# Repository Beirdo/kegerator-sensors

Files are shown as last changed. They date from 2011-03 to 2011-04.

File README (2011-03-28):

This project is licensed under the terms of GPLv2.

The hardware design was completed using the geda toolset, and my test boards
are being made by batchpcb.com.  Almost all parts purchased from digikey.com.

I will add bill of materials, etc later as time allows.

The firmware for the sensors and receiver uses the gcc-avr and avr-libc
packages for building, and avrdude for programming (with a buspirate
programmer).

In ubuntu, you will need the following debs:

For firmware:
avr-libc
avrdude
avrdude-doc
binutils-avr
gcc-avr
gdb-avr
simulavr

For schematic/circuit board:
geda
geda-doc
geda-examples
geda-gattrib
geda-gnetlist
geda-gschem
geda-gsymcheck
geda-symbols
geda-utils
gerbv
pcb
pcb-common
pcb-gtk
zip

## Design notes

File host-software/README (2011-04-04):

The host-side hardware is targeted to an ARM9TDMI board with a 3.5" touchscreen
LCD.  It can be found at:

	http://www.andahammer.com/mini35-sdk/

This board will be running Linux, and a cross-compiler suite was generated
using crosstool-ng which can be found at:

	http://ymorin.is-a-geek.org/download/crosstool-ng/

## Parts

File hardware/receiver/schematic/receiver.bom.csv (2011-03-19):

Refdes | Qty | Value | Digikey Part | Manufacturer | Manufacturer Part | Footprint | Description
CONN1,CONN2,CONN3 | 1 |  | 768-1021-ND | FTDI | MM232R |  | The jumper connectors come with the RS232-USB module
CONN4 | 1 |  | SAM1034-03-ND | Samtech | TSW-103-07-T-D | 6 pos 100" dual row | 2x3 male header
CONN5 | 1 |  | AE10334-ND | Assmann | AU-Y1008-2-R | custom | USB stacked dual-A connector
C1,C2 | 2 | 0.1uF 50V | 709-1189-1-ND | Johanson Dielectric | 500R15W104KV4T | 0805 | Capacitor Ceramic 0.1uF 50V X7R 0805
R1,R2,R3 | 3 | TBD | TBD | TBD | TBD | 0805 | Resistor Surface Mount 0805
U1 | 1 |  | ATMEGA128A-AU-ND | Atmel | ATMEAGA128A-AU | TQFP-64 | MCU 8bit 128K ISP FLASH 64-TQFP
U2 | 1 |  | TCN75AVOA-ND | Microchip | TCN75AVOA | SO-8 | IC Temp Sensor I2C 2.7V 8SOIC
U3 | 1 |  | DS92LV010ATM-ND | National Semiconductor | DS92LV010ATM | SO-8 | IC TXRX Bus LVDS Single 8SOIC

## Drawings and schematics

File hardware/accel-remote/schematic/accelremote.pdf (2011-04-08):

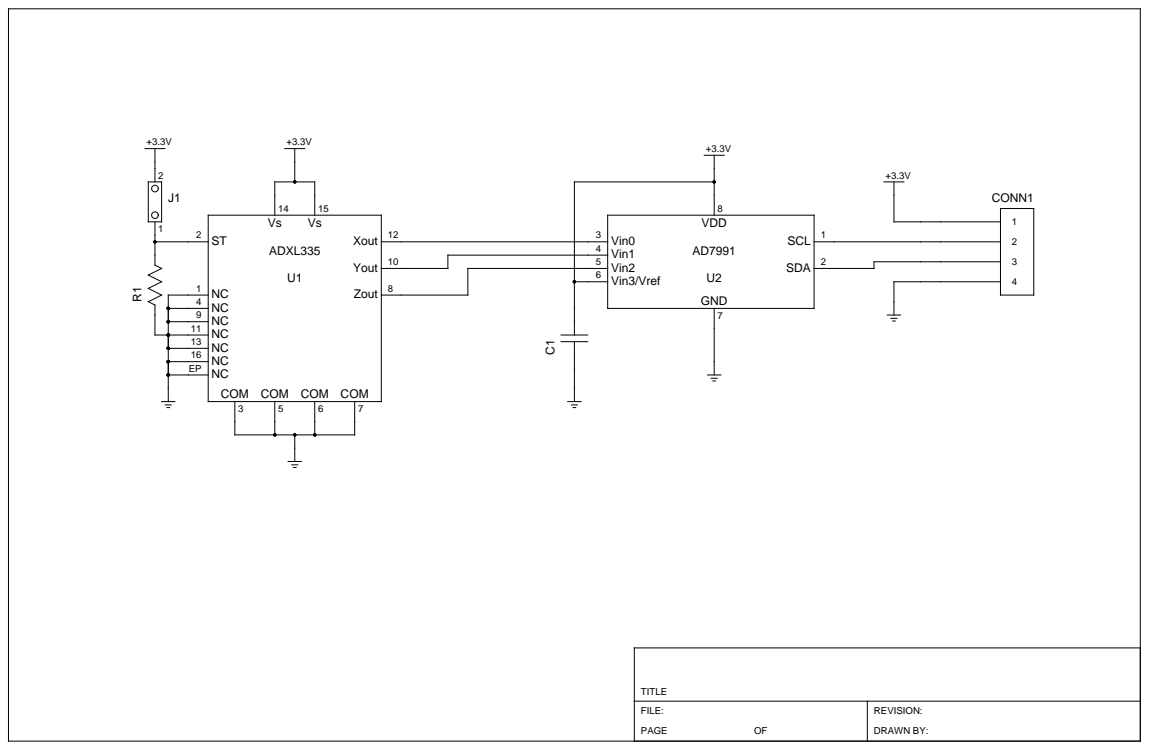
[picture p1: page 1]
PAGE; DRAWN BY:; Vin0 3; Vin3/Vref 6

NC 1 | | Vin1 4

Vin2 5

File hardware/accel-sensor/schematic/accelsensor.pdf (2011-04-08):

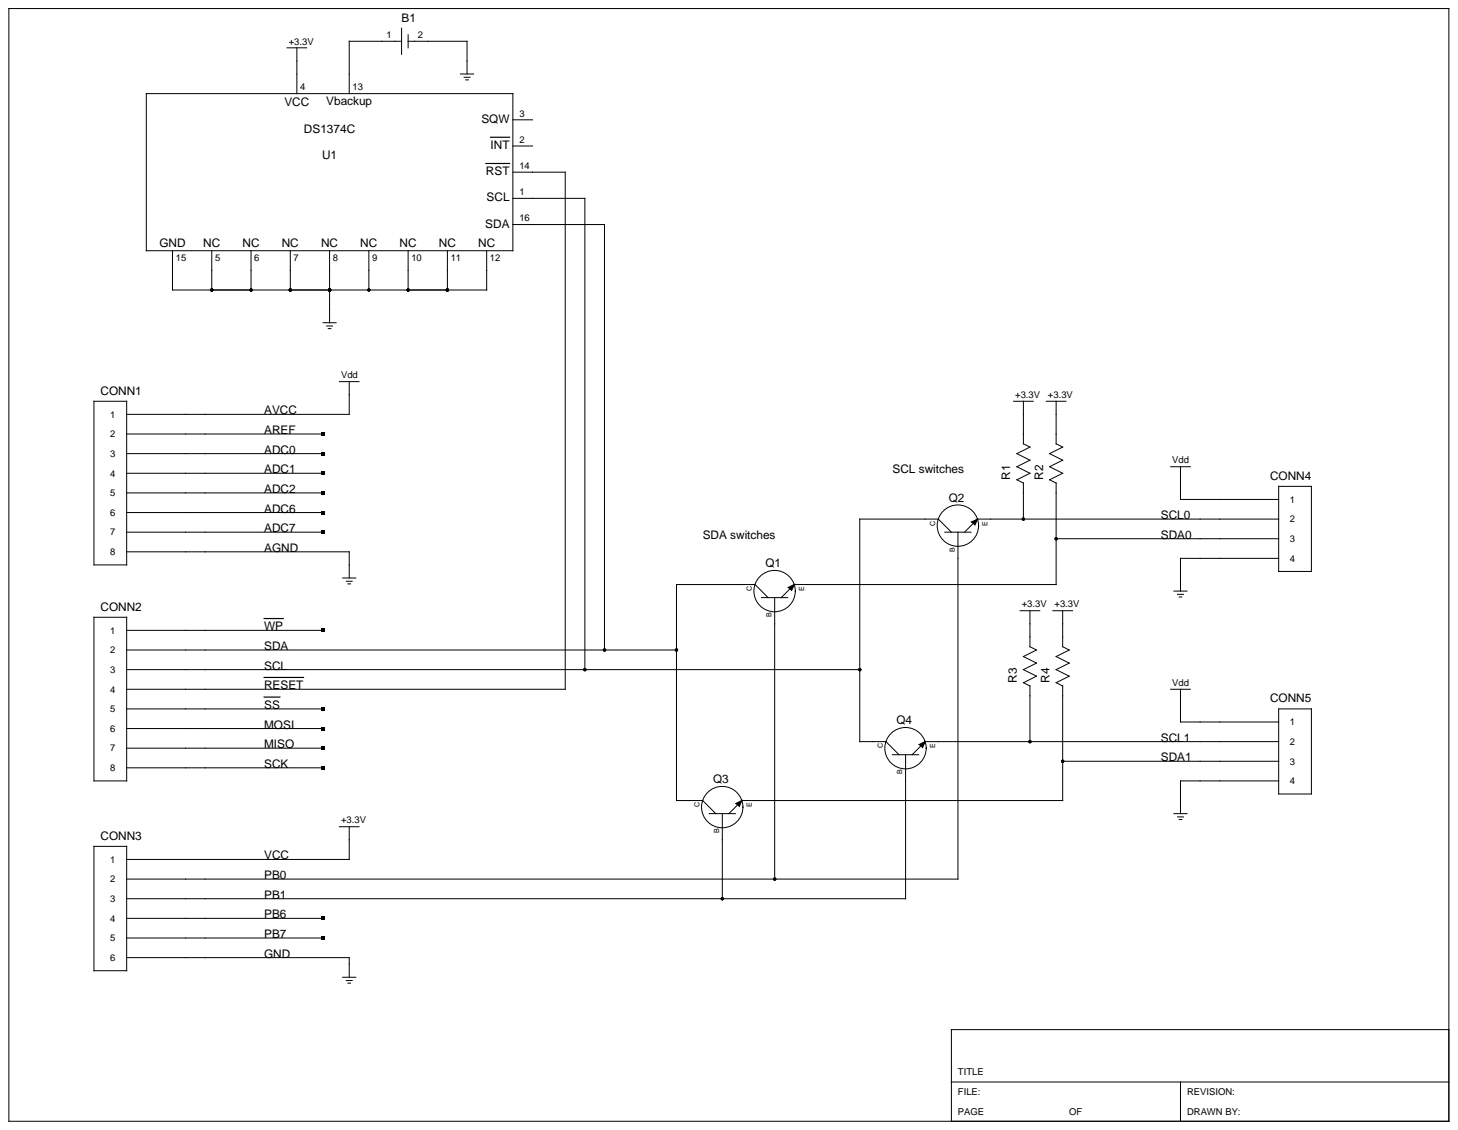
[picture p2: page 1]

SCL
RESET

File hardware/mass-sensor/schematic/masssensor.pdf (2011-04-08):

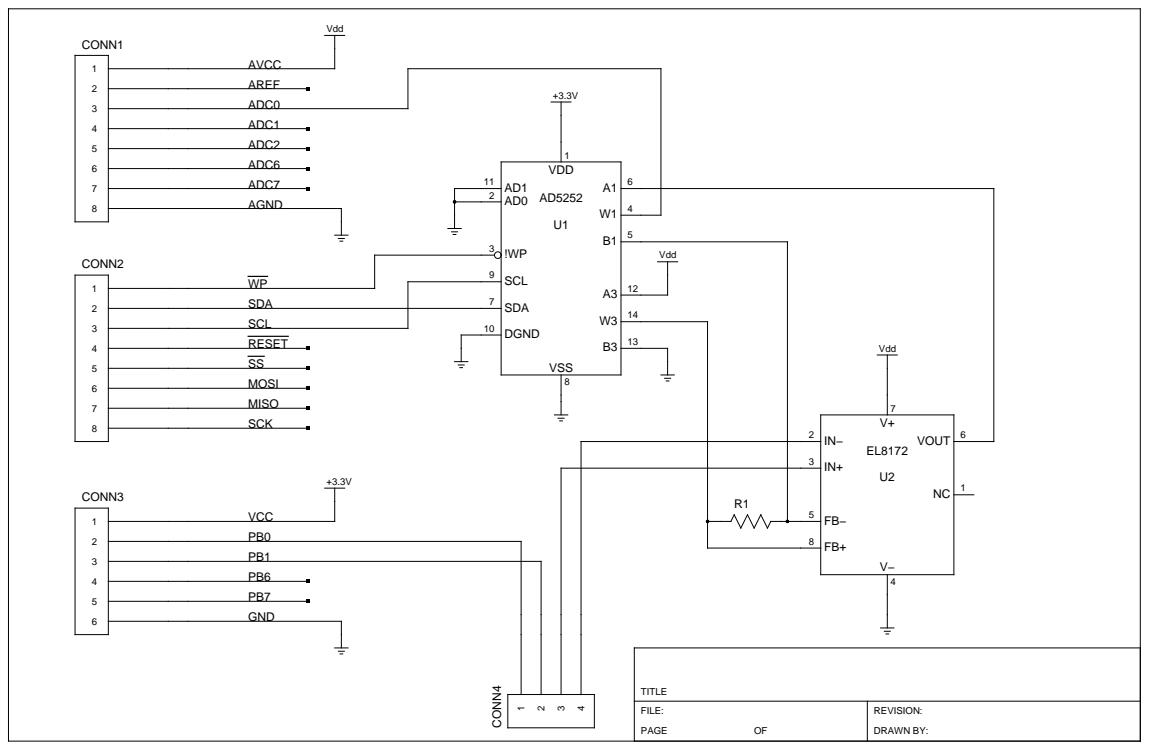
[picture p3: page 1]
PAGE; DRAWN BY:; DGND 10

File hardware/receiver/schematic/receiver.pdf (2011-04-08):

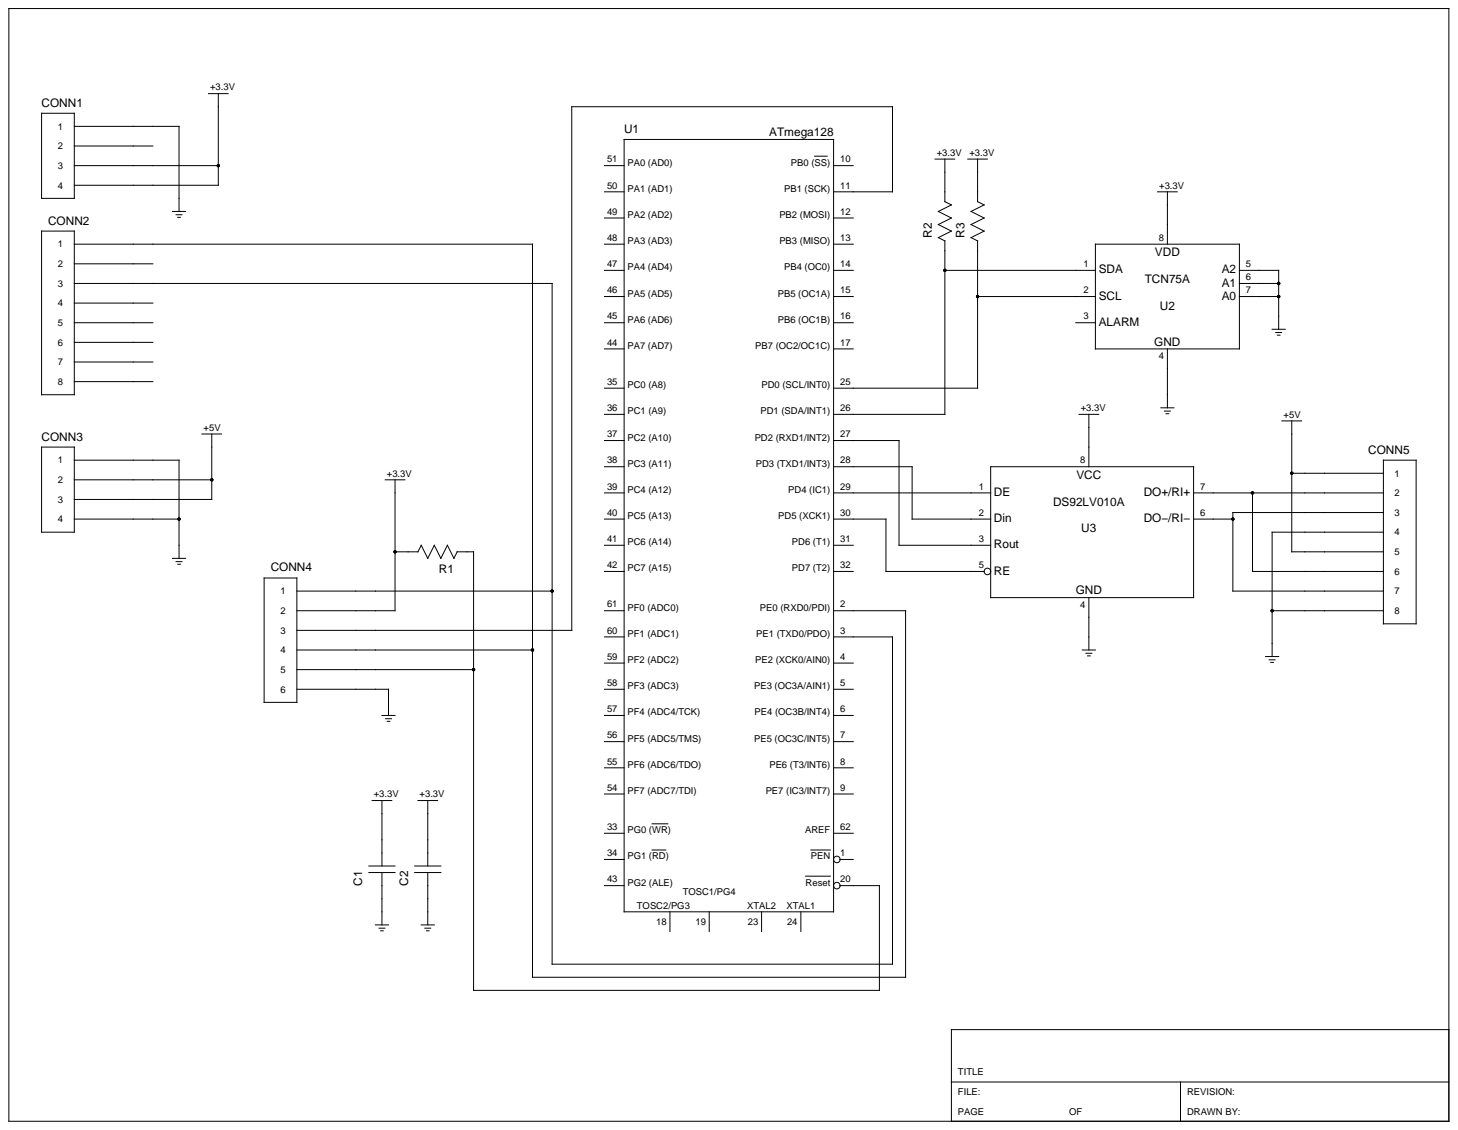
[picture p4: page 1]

30 PD5 (XCK1) | | Din 2

31 PD6 (T1) 32 PD7 (T2) 2 PE0 (RXD0/PDI) | Rout 3

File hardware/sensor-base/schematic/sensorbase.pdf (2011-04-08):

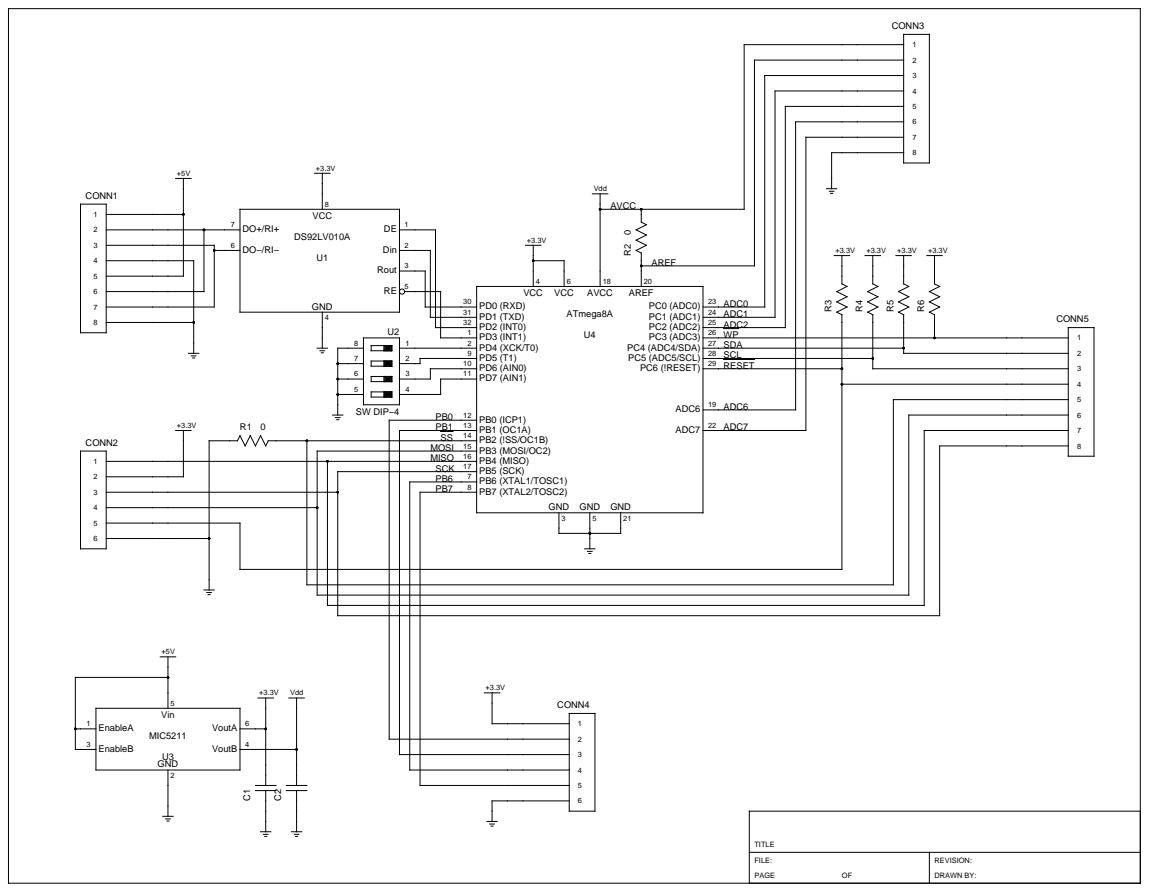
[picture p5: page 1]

SCK | PB5 (SCK) 17
PB6 | PB6 (XTAL1/TOSC1) 7

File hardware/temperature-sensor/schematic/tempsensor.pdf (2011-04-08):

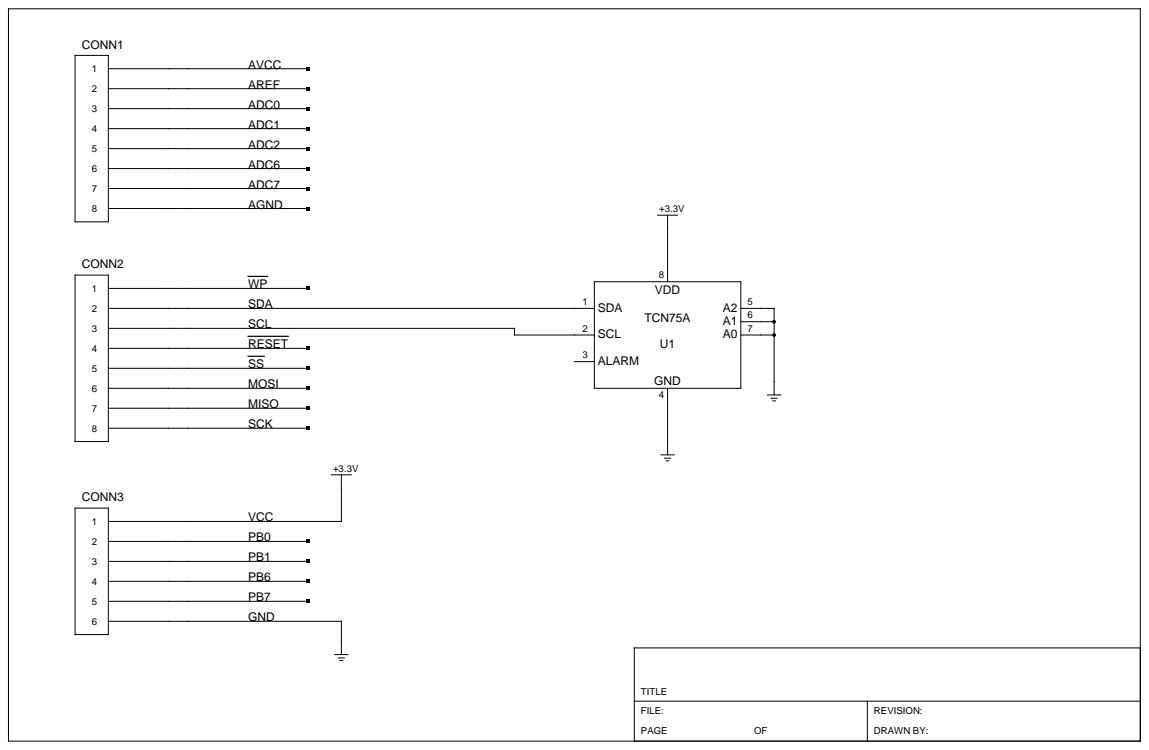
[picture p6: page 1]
PAGE; DRAWN BY:

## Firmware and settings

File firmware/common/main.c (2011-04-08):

#include "local.h"
#include <avr/io.h>
#include <avr/interrupt.h>
#include <avr/sleep.h>
#include <avr/signature.h>
#include <avr/fuse.h>
#include <util/delay.h>
#include <stdint.h>

FUSES =
{
    .low = (FUSE_CKSEL3 & FUSE_CKSEL1 & FUSE_CKSEL0 & FUSE_SUT1), 
    /* & FUSE_SUT0 & FUSE_BODEN), */
    .high = HFUSE_DEFAULT,
#if FUSE_MEMORY_SIZE == 3
    .extended = 0xFF,
#endif
};


int main(void) __attribute__((noreturn));

int main(void)
{
    cli();

    uart_setup();
    timer_setup();
    i2c_setup();
    sensor_main_setup();

    set_sleep_mode(SLEEP_MODE_IDLE);

    _delay_ms(10);

    sei();

    sensor_local_setup();

    /* Sit on this and rotate, don't return */
    while(1)
    {
        sleep_mode(); 

        if( sensor_in_use )
        {
            sensor_handle();
        }
    }
}

/*
 * vim:ts=4:sw=4:ai:et:si:sts=4
 */

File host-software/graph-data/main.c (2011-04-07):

#include <string.h>
#include <stdio.h>
#include <stdint.h>
#include <cgi.h>
#include <stdlib.h>
#include <sys/types.h>
#include <sys/stat.h>
#include <fcntl.h>
#include <unistd.h>
#include "local.h"

int main( int argc, char **argv )
{
    char   *param;
    int     sensornum;
    int     subaddr;
    int     days;
    int     type;

    cgi_init();
    cgi_process_form();

    param = cgi_param("sensor");
    sensornum = param ? atoi(param) : 255;

    param = cgi_param("type");
    type = param ? atoi(param) : S_RECEIVER;

    param = cgi_param("subaddr");
    subaddr = param ? atoi(param) : 1;

    param = cgi_param("days");
    days = param ? atoi(param) : 1;

    load_data(sensornum, subaddr, type, days );
    create_graph();

    cgi_redirect(graphuri);

    cgi_end();
    return( 0 );
}

/*
 * vim:ts=4:sw=4:ai:et:si:sts=4
 */

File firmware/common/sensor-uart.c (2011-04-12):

#include "local.h"
#include <avr/io.h>
#include <avr/interrupt.h>
#include <stdint.h>
#include <string.h>

/* 38400 to the sensors over BLVDS */
#define BAUD 38400
#include <util/setbaud.h>

uint8_t u_rx_buf[MAX_BUF_LEN];
uint8_t u_rx_index;
uint8_t u_rx_size;
uint8_t u_tx_buf[MAX_BUF_LEN];
uint8_t u_tx_index;
uint8_t u_tx_size;
uint8_t ucsra_val;

void uart_setup(void)
{
    UBRRH = UBRRH_VALUE;
    UBRRL = UBRRL_VALUE;
#if USE_2X
    ucsra_val = (1 << U2X) | (1 << MPCM);
#else
    ucsra_val = (1 << MPCM);
#endif
    UCSRA = ucsra_val;

    UCSRB = (1 << RXCIE) | (1 << RXEN) | (1 << TXEN) | (1 << UCSZ2); 
    UCSRC = (1 << URSEL) | (3 << UCSZ0);                  /* N91 */

    /* Setup the enables for the BLVDS part */
    DDRD  |= (1 << PD3) | (1 << PD2);

    /* Enable the reciever, disable the transmitter */
    PORTD &= ~((1 << PD3) | (1 << PD2));

    u_rx_index = 0;
    u_rx_size  = MAX_BUF_LEN;
    u_tx_index = 0;
}

void uart_rx_timeout(void)
{
    timer_disable();
    u_rx_index = 0;
    UCSRA = ucsra_val;
}


/* UART Rx interrupt */
ISR(SIG_UART_RECV)
{
    uint8_t byte = 0;

#if 0
    timer_enable();
#endif

    byte = UCSRB;
    byte = UDR;

    if( (UCSRA & (1 << MPCM)) ) {
        /* Wait for the address */
        if( byte != sensor_address )
            return;

        /* Allow it to read the data now */
        UCSRA = (ucsra_val & ~(1 << MPCM));
    }

    /* We are in the data portion */
    if( u_rx_index >= u_rx_size )
        return;

    u_rx_buf[u_rx_index++] = byte;

    if( u_rx_index == 2 )
    {
        u_rx_size = MIN(byte, MAX_BUF_LEN);
    }

    if( u_rx_index >= u_rx_size )
    {
        if( check_crc( u_rx_buf, u_rx_size ) != 0 )
        {
            /* Bad CRC.  */
        }
        else
        {
            /* Good CRC. */
            /* This is to this board */
            if( u_rx_size >= 6 ) {
                /* Disable RX interrupts while this runs */
                UCSRB &= ~(1 << RXCIE);

                /* Hand the buffer over to the sensor handling code */
                sensor_handle_fast();
            }
        }
        u_rx_index = 0;
        UCSRA = ucsra_val;
    }
}

/* UART Tx Data Empty interrupt */
ISR(SIG_UART_DATA)
{
    if( u_tx_index == u_tx_size )
    {
        UCSRB &= ~(1 << UDRIE);
    }
    else
    {
        UCSRB &= ~(1 << TXB8);  /* In data mode, no address bit */
        UDR = u_tx_buf[u_tx_index++];
    }
}

/* UART Tx Complete interrupt */
ISR(SIG_UART_TRANS)
{
    UCSRB &= ~(1 << TXCIE);

    /* Enable the reciever, disable the transmitter */
    PORTD &= ~((1 << PD3) | (1 << PD2));

    u_tx_size = 0;
}

void uart_transmit(void)
{
    u_tx_size = MIN(u_tx_size, MAX_BUF_LEN);
    if( u_tx_size )
    {
        /* Enable the transmitter, disable the receiver */
        PORTD |= (1 << PD3) | (1 << PD2);

        u_tx_index = 0;
        UCSRB |= (1 << TXB8);  /* Set the address bit */
        UDR = 0xFF;
        UCSRB |= (1 << TXCIE) | (1 << UDRIE);
    }
}

void uart_restart_rx(void)
{
    uint8_t dummy;

    /* Drain the RX register */
    while( UCSRA & (1 << RXC) ) 
        dummy = UDR;

    u_rx_index = 0;
    UCSRA = ucsra_val;

    /* Reenable RX interrupts */
    UCSRB |= (1 << RXCIE);
}


/*
 * vim:ts=4:sw=4:ai:et:si:sts=4
 */

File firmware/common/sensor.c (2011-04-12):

#include "local.h"
#include <avr/io.h>
#include <avr/interrupt.h>
#include <util/delay.h>
#include <stdint.h>
#include <string.h>

uint8_t sensor_address;
volatile uint8_t sensor_in_use = 0;
volatile uint8_t sensor_buf[MAX_BUF_LEN];
volatile uint8_t sensor_size;

void sensor_common_setup(void)
{
    /* Make the DIP switch bits (PD7-4) inputs, pull up resistor enabled */
    DDRD  &= 0x0F;
    PORTD |= 0xF0;

    /* Let the inputs settle */
    _delay_ms(10);

    /* Read the DIP switch */
    sensor_address = PIND >> 4;
}

void sensor_handle_fast(void)
{
    memcpy((uint8_t *)sensor_buf, u_rx_buf, u_rx_size);
    sensor_size = u_rx_size;
    sensor_in_use = 1;
}

void sensor_handle(void)
{
    message *msg;
    uint16_t crc;

    sensor_in_use = 0;

    msg = (message *)u_rx_buf;

    if( msg->get_set )
    {
        if( !sensor_handle_set(msg) )
            return;
    }
    else
    {
        if( !sensor_handle_get(msg) )
            return;
    }

    u_tx_buf[1] = u_tx_size;

    crc = calc_crc( u_tx_buf, u_tx_size-2 );

    u_tx_buf[u_tx_size-2] = (crc & 0xFF);
    u_tx_buf[u_tx_size-1] = (crc >> 8);

    uart_transmit();
    uart_restart_rx();
}

/*
 * vim:ts=4:sw=4:ai:et:si:sts=4
 */

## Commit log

2011-03-16 Initial commit with hardware for receiver and temp sensor
    [receiver.back.gbr, receiver.backmask.gbr, receiver.backpaste.gbr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]
2011-03-19 Added BOM files (in CSV format)
    Referenced are Digikey part numbers for easier ordering
    [receiver.bom.csv, tempsensor.bom.csv]
2011-03-19 Add first run at a mass sensor board
    Using a Wheatstone bridge with a strain gauge as a resistive element in one
    arm of the bridge. This will be done by hacking shipping or bathroom scales.
    There is provision to adjust both the gain and the offset of the amplified
    voltage before feeding it to an ADC.
    [masssensor.back.gbr, masssensor.backmask.gbr, masssensor.backpaste.gbr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]
2011-03-20 New base board for modular sensors
    Rather than build the same board numerous times, I'm thinking of redoing all
    the sensors to be modular and share the core parts.
    [sensorbase.back.gbr, sensorbase.backmask.gbr, sensorbase.backpaste.gbr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]
2011-03-20 Reorganizing to redo sensors as modules
    [masssensor.back.gbr, masssensor.backmask.gbr, masssensor.backpaste.gbr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]
2011-03-20 Convert temperature and mass sensors to modules
    [masssensor.back.gbr, masssensor.backmask.gbr, masssensor.backpaste.gbr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]
2011-03-21 Modified Sensor Base board to pass DRC
    [sensorbase.back.gbr, sensorbase.backmask.gbr, sensorbase.backpaste.gbr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]
2011-03-21 Add Accelerometer Remote (attaches to beer tap)
    [accelremote.back.gbr, accelremote.backmask.gbr, accelremote.backpaste.gbr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]
2011-03-21 Add Accelerometer Sensor (connects to 2 Accelerometer Remotes)
    [accelsensor.back.gbr, accelsensor.backmask.gbr, accelsensor.backpaste.gbr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]
2011-03-22 Forgot the gerbers staging dir.
2011-03-22 Remove the old dir.
    [masssensor.back.gbr, masssensor.backmask.gbr, masssensor.backpaste.gbr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]
2011-03-22 Flesh out the message structure received on UART0
2011-03-23 Fix stupid speeling error
    [receiver.bom.csv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]
2011-03-23 Add prototype for the sensor_handle() routine
2011-03-23 Added first-run at temperature sensor firmware
2011-03-24 Add initial firmware for mass sensors
2011-03-24 Added fuses and put clock to 8MHz
2011-03-24 First run at accelerometer sensor firmware
2011-03-24 Updated the I2C code so it's common again
2011-03-24 Add sensor type to the firmware string.
2011-03-25 Combined the local.h -> common.h/sensor-common.h
2011-03-25 Consolidated sensor.c, created local.c
2011-03-28 Add support to extract each fuse value to txt file
    This will make it easier to program the fuses with avrdude later.
2011-03-29 Moved hardware stuff under hardware/
    [accelremote.back.gbr, accelremote.backmask.gbr, accelremote.backpaste.gbr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]
2011-04-04 Add program-check, fix fuse programming
2011-04-04 Make some stuff volatile, calc TX CRC correctly
    [local.c, sensor.c]
2011-04-04 Fix UART Rx interrupts so they will actually work.
    [sensor-uart.c, uart0.c, uart1.c]
2011-04-04 Add first run at host-side polling
    This will be running on a mini2440 board (ARM9TDMI) running Linux
2011-04-04 Change fuses so this works. Move sleep def. earlier.
2011-04-06 Fix the I2C state machine to actually work
    Also changed enum -> uint8 to save space and time.
    [i2c.c]
2011-04-06 Fix tcn75_read to allow proper reads from any reg
    The return from the config reg will be stuffed into the LSB of a uint16
    [tcn75a.c]
2011-04-06 Fix temperature setting scaling
    Also cleaned up the console logging a touch.
2011-04-06 Tweak sensor local.c
2011-04-07 Added CGI app to graph the sensor data
    Runs on the ARM9TDMI
2011-04-08 Add a 100bit-time timer on LVDS UART
2011-04-08 Add 100 bittime timer on UART to PC
2011-04-08 Added PDFs of the schematics
2011-04-08 Streamline the serial code, make it more resiliant
    Also streamline the sensor polling to be more loop driven.
2011-04-10 Redo the LVDO to the correct (I HOPE!) SOT23-6 layout
    Also rerouted a bunch of other stuff for simplicity/better flow.
    [sensorbase.back.gbr, sensorbase.backmask.gbr, sensorbase.backpaste.gbr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]
2011-04-11 Add a breakout/convert board for the buspirate
    [breakout.sch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]
2011-04-12 Get the 9-bit MPCM mostly working on sensor-uart
    It seems to only receive one packet on the sensor baord before ignoring the
    rest.
2011-04-12 Fixed the UART restart (& rather than &&)
    Also some misc. cleanup.
    [local.c, sensor-uart.c, sensor.c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]
2011-04-12 Temperatures are in two's complement. Duh.
2011-04-13 Added tool to calibrate mass sensors
